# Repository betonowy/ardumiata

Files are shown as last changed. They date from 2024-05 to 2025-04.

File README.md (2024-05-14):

# Engine health monitoring for Mazda MX-5 NB1

Firmware for custom Arduino Nano powered device. Mainly for precise engine health monitoring on track days. Features:

- Invisible, non-invasive piggyback off of factory wiring harness if needed at all.
- Modifications are reversible.
- Cleanly integrates with car's interior. 16x2 green display can replace smoking ashtray on NB1. I made a "mounting bracket" for it with a matte painted piece of wood.
- Monitoring engine health and more:
    - (ECT) Coolant temperature - piggybacked and calibrated against factory sensor and ECU measurement circuit. May alternatively use temp gauge circuit, but you're on your own to deal with that.
    - (EOT) Oil temperatoure - from Ecumaster Temperature Sensor.
    - (EOP) Oil pressure - from Ecumaster Pressure Sensor.
    - (BAT) Battery voltage (from ignition).
- Alarm when any measurement exceeds safe limits so you know when to cooldown or make an emergency shutdown.
- If your ECT ever breaks, you will know.

## Important notes

- ECT approximation function might need to be recalibrated/curve fitted for any other car than mine, especially if any part of PCB design is altered. Measuring temperatures/ECT voltage at the back of the engine with device attached and compensating for measured voltages when fan switches on and off at 97C and 93C is good enough, especially if you just need a relative guide for how hot the engine is. If outside EU, check your regional specs specifically.
- Despite the efforts, cabin fan can offset measurements up to 4 degrees upwards when on and it can't be fixed, take that into account or don't turn it.
- ECT relay is required to ensure device does not affect ECU measurements when device is in an inconsistent state i.e. during reset, or engine startup.
- Cars with no AC have a very convenient rubber cap that can feed wires through passenger side firewall.

# Building project

- PCB project initially made in KiCad 8.
- Source compilled with `avr-gcc` toolchain with Arduino package. For guide check out `Arduino-CMake-NG` project. Initially developed on a Linux system.

Assuming basic KiCad and CMake knowledge, you should already know how to build the project.

## Project layout

- `.` - miscelaneous files and root `CMakeLists.txt`.
- `src` - Firmware source code.
- `kicad` - KiCad PCB project.

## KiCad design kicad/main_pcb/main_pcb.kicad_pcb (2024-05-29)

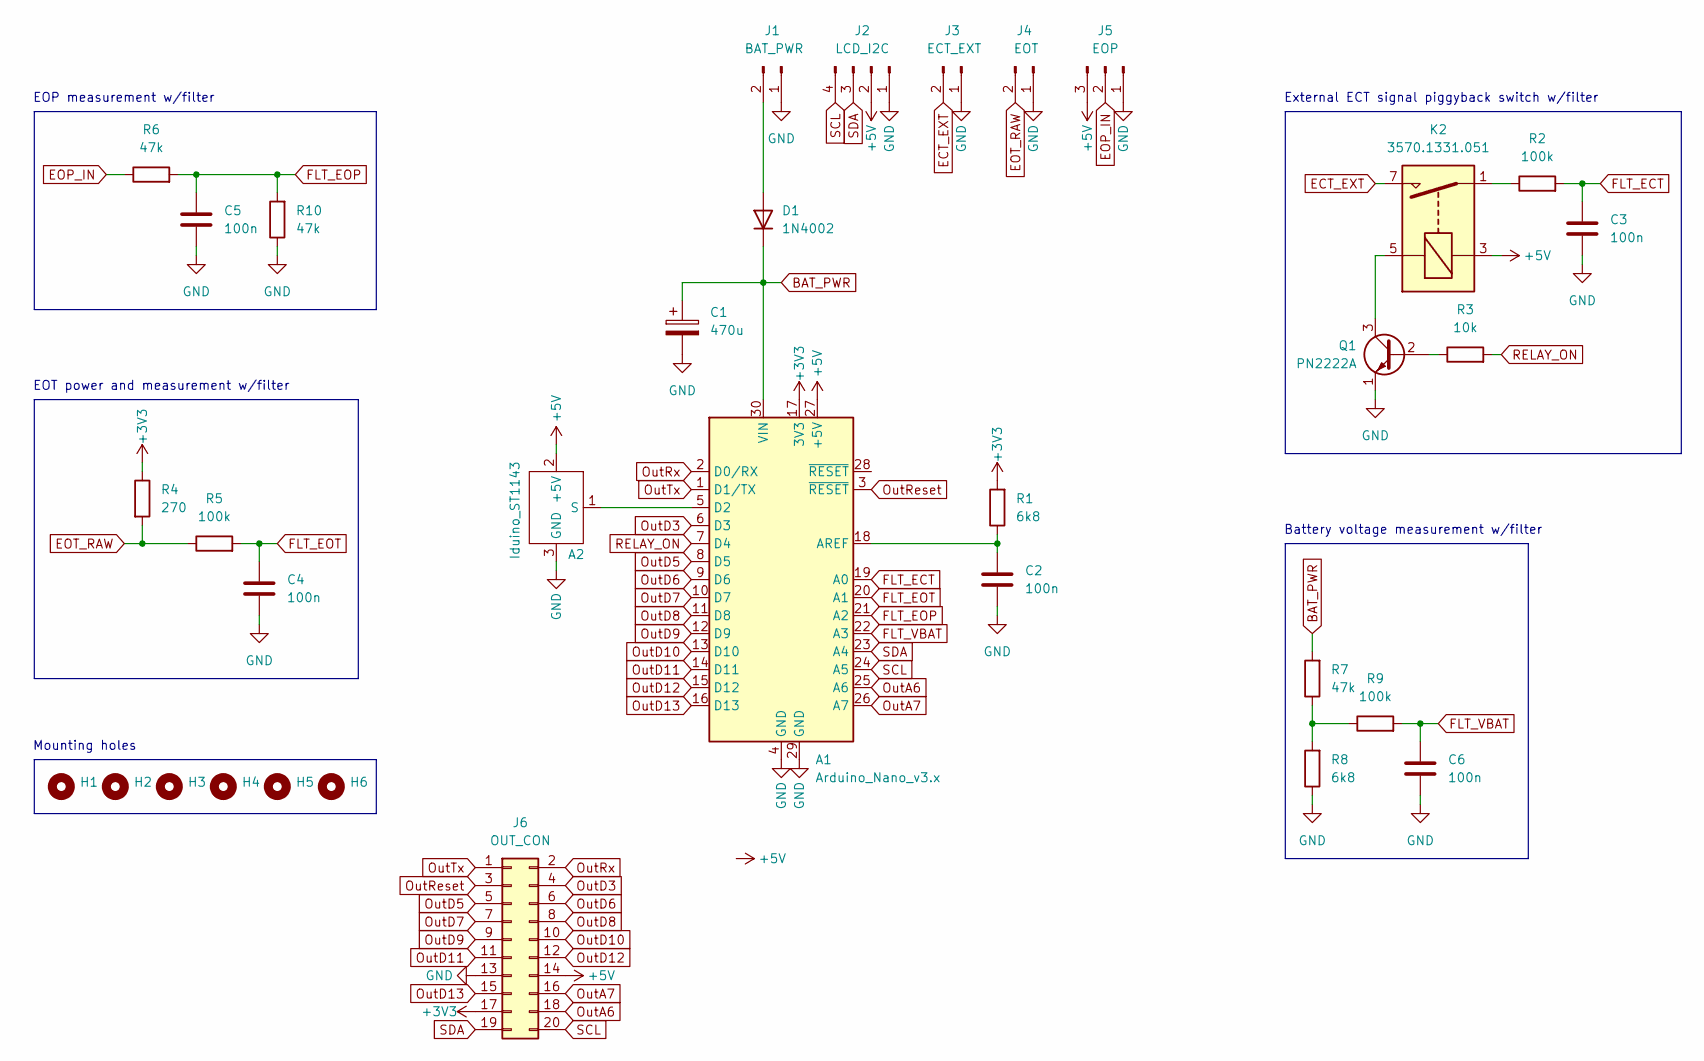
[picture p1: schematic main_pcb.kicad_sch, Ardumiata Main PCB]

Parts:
A1: Arduino_Nano_v3.x; Arduino_Nano
A2: Iduino_ST1143
C1: 470u; CP_Radial_D10.0mm_P5.00mm
C2, C3, C4, C5, C6: 100n; C_Disc_D3.8mm_W2.6mm_P2.50mm
D1: 1N4002; D_DO-41_SOD81_P10.16mm_Horizontal
H1, H2, H3, H4, H5, H6: MountingHole_3.5mm
J1: BAT_PWR; Molex_KK-254_AE-6410-02A_1x02_P2.54mm_Vertical
J2: LCD_I2C; Molex_KK-254_AE-6410-04A_1x04_P2.54mm_Vertical
J3: ECT_EXT; Molex_KK-254_AE-6410-02A_1x02_P2.54mm_Vertical
J4: EOT; Molex_KK-254_AE-6410-02A_1x02_P2.54mm_Vertical
J5: EOP; Molex_KK-254_AE-6410-03A_1x03_P2.54mm_Vertical
J6: OUT_CON; IDC-Header_2x10_P2.54mm_Vertical
K2: 3570.1331.051; Relay_SPST_StandexMeder_SIL_Form1A
Q1: PN2222A; TO-92_Inline
R1, R8: 6k8; R_Axial_DIN0207_L6.3mm_D2.5mm_P7.62mm_Horizontal
R2, R5, R9: 100k; R_Axial_DIN0207_L6.3mm_D2.5mm_P7.62mm_Horizontal
R3: 10k; R_Axial_DIN0207_L6.3mm_D2.5mm_P7.62mm_Horizontal
R4: 270; R_Axial_DIN0207_L6.3mm_D2.5mm_P7.62mm_Horizontal
R6, R7, R10: 47k; R_Axial_DIN0207_L6.3mm_D2.5mm_P7.62mm_Horizontal

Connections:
+3V3: A1.17 (3V3), J6.17, R1.2, R4.1
+5V: A1.27 (+5V), A2.2 (+5V), J2.2, J5.3, J6.14, K2.3
BAT_PWR: A1.30 (VIN), C1.1, D1.1 (K), R7.2
ECT_EXT: J3.2, K2.7
EOP_IN: J5.2, R6.1
EOT_RAW: J4.2, R4.2, R5.1
FLT_ECT: A1.19 (A0), C3.1, R2.2
FLT_EOP: A1.21 (A2), C5.1, R6.2, R10.2
FLT_EOT: A1.20 (A1), C4.1, R5.2
FLT_VBAT: A1.22 (A3), C6.1, R9.2
GND: A1.4 (GND), A1.29 (GND), A2.3 (GND), C1.2, C2.2, C3.2, C4.2, C5.2, C6.2, J1.1, J2.1, J3.1, J4.1, J5.1, J6.13, Q1.1 (E), R8.1, R10.1
unnamed: A1.18 (AREF), C2.1, R1.1
unnamed: A1.5 (D2), A2.1 (S)
unnamed: D1.2 (A), J1.2
unnamed: K2.1, R2.1
unnamed: Q1.2 (B), R3.1
unnamed: K2.5, Q1.3 (C)
unnamed: R7.1, R8.2, R9.1
OutA6: A1.25 (A6), J6.18
OutA7: A1.26 (A7), J6.16
OutD3: A1.6 (D3), J6.4
OutD5: A1.8 (D5), J6.5
OutD6: A1.9 (D6), J6.6
OutD7: A1.10 (D7), J6.7
OutD8: A1.11 (D8), J6.8
OutD9: A1.12 (D9), J6.9
OutD10: A1.13 (D10), J6.10
OutD11: A1.14 (D11), J6.11
OutD12: A1.15 (D12), J6.12
OutD13: A1.16 (D13), J6.15
OutReset: A1.3 (~RESET), J6.3
OutRx: A1.2 (D0/RX), J6.2
OutTx: A1.1 (D1/TX), J6.1
RELAY_ON: A1.7 (D4), R3.2
SCL: A1.24 (A5), J2.4, J6.20
SDA: A1.23 (A4), J2.3, J6.19

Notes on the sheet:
EOP measurement w/filter
Battery voltage measurement w/filter
External ECT signal piggyback switch w/filter
Mounting holes
EOT power and measurement w/filter

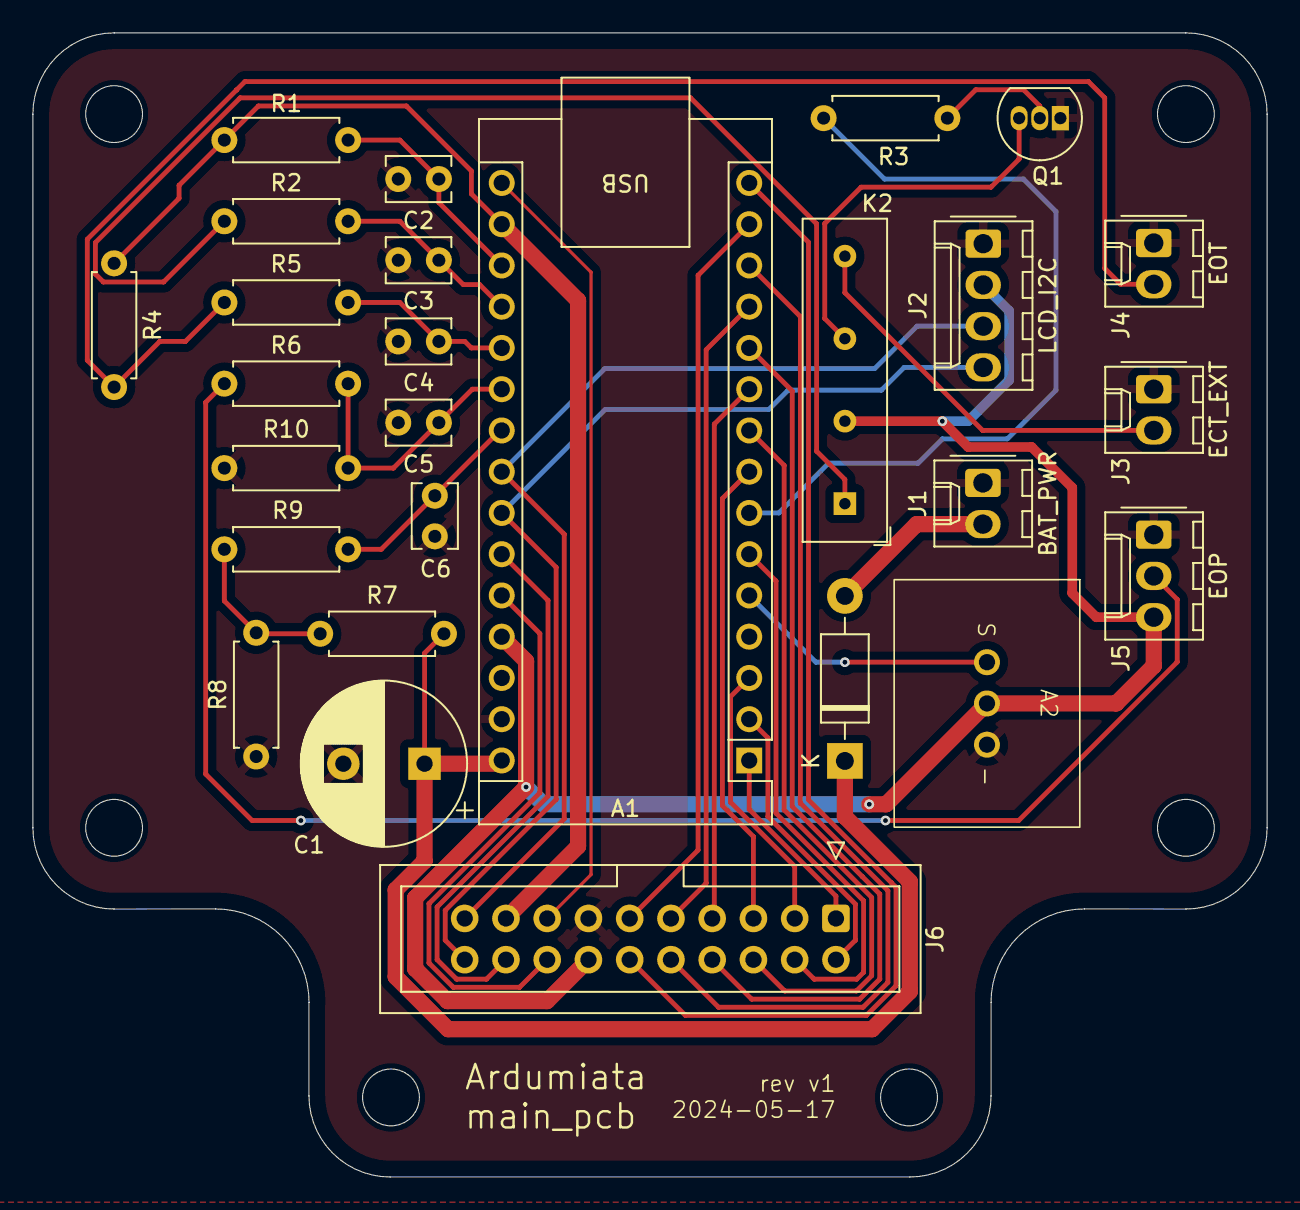
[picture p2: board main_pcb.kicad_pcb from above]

Board: 2 copper layers, 76.0 x 70.4 mm, 33 parts (0 on the bottom side), 36 nets.

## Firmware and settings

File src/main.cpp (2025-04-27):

#include <Arduino.h>

#include "buzzer.hpp"
#include "display.hpp"
#include "sensors.hpp"
#include "voltage.hpp"

void setup()
{
    analogReference(EXTERNAL);
    setupBuzzer();
    setupDisplay();

    pinMode(4, OUTPUT);
    digitalWrite(4, HIGH);

    // Beep to signal setup completion
    setBuzzer(true);
    delay(30);
    setBuzzer(false);
}

void updatePeriodicalReadings()
{
    ectUpdateRaw(hardenedAnalogRead(A0));
    eotUpdateRaw(hardenedAnalogRead(A1));
    eopUpdateRaw(hardenedAnalogRead(A2));

    {
        setSlotIcon(DisplaySlot::UL, Icon::OIL, Icon::TEMP);

        switch (eotIsValid())
        {
        case SensorRange::OK:
            setSlot(DisplaySlot::UL, eotGetCelsius());
            break;
        case SensorRange::TOO_LOW:
            setSlot(DisplaySlot::UL, "Cold");
            break;
        case SensorRange::TOO_HIGH:
            setSlot(DisplaySlot::UL, "Hot");
        }
    }
    {
        setSlotIcon(DisplaySlot::UR, Icon::OIL, Icon::PRESSURE);

        switch (eopIsValid())
        {
        case SensorRange::OK:
        case SensorRange::OK_DISABLE_ALARM:
            setSlot(DisplaySlot::UR, eopGetBar());
            break;
        case SensorRange::TOO_LOW:
            setSlot(DisplaySlot::UR, 0.0f);
            break;
        case SensorRange::TOO_HIGH:
            setSlot(DisplaySlot::UR, 10.0f);
        }
    }
    {
        setSlotIcon(DisplaySlot::BL, Icon::WATER, Icon::TEMP);

        switch (ectIsValid())
        {
        case SensorRange::OK:
            setSlot(DisplaySlot::BL, ectGetCelsius());
            break;
        case SensorRange::TOO_LOW:
            setSlot(DisplaySlot::BL, "Cold");
            break;
        case SensorRange::TOO_HIGH:
            setSlot(DisplaySlot::BL, "Hot");
        }
    }
    {
        setSlotIcon(DisplaySlot::BR, Icon::BAT_A, Icon::BAT_B);
        setSlot(DisplaySlot::BR, getVoltage());
    }
}

namespace
{
constexpr auto safeCoolantTempLimit = 115.f;
constexpr auto safeOilTempLimit = 130.f;
constexpr auto safePressureLimitLow = 0.65f;
constexpr auto safePressureLimitHigh = 6.0f;
} // namespace

void updateAlarm()
{
    bool turnOnAlarm = false;

    turnOnAlarm |= ectGetCelsius() > safeCoolantTempLimit && ectIsValid() == SensorRange::OK;
    turnOnAlarm |= eotGetCelsius() > safeOilTempLimit && eotIsValid() == SensorRange::OK;
    turnOnAlarm |= eopGetBar() > safePressureLimitHigh && eopIsValid() == SensorRange::OK;
    turnOnAlarm |= eopGetBar() < safePressureLimitLow && eopIsValid() == SensorRange::OK;

    if (turnOnAlarm)
    {
        setBuzzer(true);
    }
    else
    {
        setBuzzer(false);
    }
}

unsigned long nextUpdateTime = 0;
unsigned long screenDelay = 250;

bool shouldUpdateDisplay()
{
    const uint32_t time = millis();

    if (static_cast<int32_t>(nextUpdateTime - time) > 0)
    {
        return false;
    }

    nextUpdateTime = time + screenDelay;

    return true;
}

void loop()
{
    if (shouldUpdateDisplay())
    {
        updatePeriodicalReadings();
        updateDisplay();
        updateAlarm();
    }

    loopBuzzer();
}

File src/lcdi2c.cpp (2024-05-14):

#include "lcdi2c.hpp"
#include <Arduino.h>
#include <Wire.h>

// When the display powers up, it is configured as follows:
//
// 1. Display clear
// 2. Function set:
//    DL = 1; 8-bit interface data
//    N = 0; 1-line display
//    F = 0; 5x8 dot character font
// 3. Display on/off control:
//    D = 0; Display off
//    C = 0; Cursor off
//    B = 0; Blinking off
// 4. Entry mode set:
//    I/D = 1; Increment by 1
//    S = 0; No shift
//
// Note, however, that resetting the Arduino doesn't reset the LCD, so we
// can't assume that its in that state when a sketch starts (and the
// LiquidCrystal constructor is called).

LiquidCrystal_I2C::LiquidCrystal_I2C(uint8_t lcd_addr, uint8_t lcd_cols, uint8_t lcd_rows, uint8_t charsize)
{
    _addr = lcd_addr;
    _cols = lcd_cols;
    _rows = lcd_rows;
    _charsize = charsize;
    _backlightval = LCD_BACKLIGHT;
}

void LiquidCrystal_I2C::begin()
{
    Wire.begin();
    _displayfunction = LCD_4BITMODE | LCD_1LINE | LCD_5x8DOTS;

    if (_rows > 1)
    {
        _displayfunction |= LCD_2LINE;
    }

    // for some 1 line displays you can select a 10 pixel high font
    if ((_charsize != 0) && (_rows == 1))
    {
        _displayfunction |= LCD_5x10DOTS;
    }

    // SEE PAGE 45/46 FOR INITIALIZATION SPECIFICATION!
    // according to datasheet, we need at least 40ms after power rises above 2.7V
    // before sending commands. Arduino can turn on way befer 4.5V so we'll wait 50
    delay(50);

    // Now we pull both RS and R/W low to begin commands
    expanderWrite(_backlightval); // reset expanderand turn backlight off (Bit 8 =1)
    delay(1000);

    // put the LCD into 4 bit mode
    //  this is according to the hitachi HD44780 datasheet
    //  figure 24, pg 46

    // we start in 8bit mode, try to set 4 bit mode
    write4bits(0x03 << 4);
    delayMicroseconds(4500); // wait min 4.1ms

    // second try
    write4bits(0x03 << 4);
    delayMicroseconds(4500); // wait min 4.1ms

    // third go!
    write4bits(0x03 << 4);
    delayMicroseconds(150);

    // finally, set to 4-bit interface
    write4bits(0x02 << 4);

    // set # lines, font size, etc.
    command(LCD_FUNCTIONSET | _displayfunction);

    // turn the display on with no cursor or blinking default
    _displaycontrol = LCD_DISPLAYON | LCD_CURSOROFF | LCD_BLINKOFF;
    display();

    // clear it off
    clear();

    // Initialize to default text direction (for roman languages)
    _displaymode = LCD_ENTRYLEFT | LCD_ENTRYSHIFTDECREMENT;

    // set the entry mode
    command(LCD_ENTRYMODESET | _displaymode);

    home();
}

/********** high level commands, for the user! */
void LiquidCrystal_I2C::clear()
{
    command(LCD_CLEARDISPLAY); // clear display, set cursor position to zero
    delayMicroseconds(2000);   // this command takes a long time!
}

void LiquidCrystal_I2C::home()
{
    command(LCD_RETURNHOME); // set cursor position to zero
    delayMicroseconds(2000); // this command takes a long time!
}

void LiquidCrystal_I2C::setCursor(uint8_t col, uint8_t row)
{
    int row_offsets[] = {0x00, 0x40, 0x14, 0x54};
    if (row > _rows)
    {
        row = _rows - 1; // we count rows starting w/0
    }
    command(LCD_SETDDRAMADDR | (col + row_offsets[row]));
}

// Turn the display on/off (quickly)
void LiquidCrystal_I2C::noDisplay()
{
    _displaycontrol &= ~LCD_DISPLAYON;
    command(LCD_DISPLAYCONTROL | _displaycontrol);
}
void LiquidCrystal_I2C::display()
{
    _displaycontrol |= LCD_DISPLAYON;
    command(LCD_DISPLAYCONTROL | _displaycontrol);
}

// Turns the underline cursor on/off
void LiquidCrystal_I2C::noCursor()
{
    _displaycontrol &= ~LCD_CURSORON;
    command(LCD_DISPLAYCONTROL | _displaycontrol);
}
void LiquidCrystal_I2C::cursor()
{
    _displaycontrol |= LCD_CURSORON;
    command(LCD_DISPLAYCONTROL | _displaycontrol);
}

// Turn on and off the blinking cursor
void LiquidCrystal_I2C::noBlink()
{
    _displaycontrol &= ~LCD_BLINKON;
    command(LCD_DISPLAYCONTROL | _displaycontrol);
}
void LiquidCrystal_I2C::blink()
{
    _displaycontrol |= LCD_BLINKON;
    command(LCD_DISPLAYCONTROL | _displaycontrol);
}

// These commands scroll the display without changing the RAM
void LiquidCrystal_I2C::scrollDisplayLeft(void)
{
    command(LCD_CURSORSHIFT | LCD_DISPLAYMOVE | LCD_MOVELEFT);
}
void LiquidCrystal_I2C::scrollDisplayRight(void)
{
    command(LCD_CURSORSHIFT | LCD_DISPLAYMOVE | LCD_MOVERIGHT);
}

// This is for text that flows Left to Right
void LiquidCrystal_I2C::leftToRight(void)
{
    _displaymode |= LCD_ENTRYLEFT;
    command(LCD_ENTRYMODESET | _displaymode);
}

// This is for text that flows Right to Left
void LiquidCrystal_I2C::rightToLeft(void)
{
    _displaymode &= ~LCD_ENTRYLEFT;
    command(LCD_ENTRYMODESET | _displaymode);
}

// This will 'right justify' text from the cursor
void LiquidCrystal_I2C::autoscroll(void)
{
    _displaymode |= LCD_ENTRYSHIFTINCREMENT;
    command(LCD_ENTRYMODESET | _displaymode);
}

// This will 'left justify' text from the cursor
void LiquidCrystal_I2C::noAutoscroll(void)
{
    _displaymode &= ~LCD_ENTRYSHIFTINCREMENT;
    command(LCD_ENTRYMODESET | _displaymode);
}

// Allows us to fill the first 8 CGRAM locations
// with custom characters
void LiquidCrystal_I2C::createChar(uint8_t location, const uint8_t charmap[])
{
    location &= 0x7; // we only have 8 locations 0-7
    command(LCD_SETCGRAMADDR | (location << 3));
    for (int i = 0; i < 8; i++)
    {
        write(charmap[i]);
    }
}

// Turn the (optional) backlight off/on
void LiquidCrystal_I2C::noBacklight(void)
{
    _backlightval = LCD_NOBACKLIGHT;
    expanderWrite(0);
}

void LiquidCrystal_I2C::backlight(void)
{
    _backlightval = LCD_BACKLIGHT;
    expanderWrite(0);
}
bool LiquidCrystal_I2C::getBacklight()
{
    return _backlightval == LCD_BACKLIGHT;
}

/*********** mid level commands, for sending data/cmds */

inline void LiquidCrystal_I2C::command(uint8_t value)
{
    send(value, 0);
}

inline size_t LiquidCrystal_I2C::write(uint8_t value)
{
    send(value, Rs);
    return 1;
}

/************ low level data pushing commands **********/

// write either command or data
void LiquidCrystal_I2C::send(uint8_t value, uint8_t mode)
{
    uint8_t highnib = value & 0xf0;
    uint8_t lownib = (value << 4) & 0xf0;
    write4bits((highnib) | mode);
    write4bits((lownib) | mode);
}

void LiquidCrystal_I2C::write4bits(uint8_t value)
{
    expanderWrite(value);
    pulseEnable(value);
}

void LiquidCrystal_I2C::expanderWrite(uint8_t _data)
{
    Wire.beginTransmission(_addr);
    Wire.write((int)(_data) | _backlightval);
    Wire.endTransmission();
}

void LiquidCrystal_I2C::pulseEnable(uint8_t _data)
{
    expanderWrite(_data | En); // En high
    delayMicroseconds(1);      // enable pulse must be >450ns

    expanderWrite(_data & ~En); // En low
    delayMicroseconds(50);      // commands need > 37us to settle
}

void LiquidCrystal_I2C::load_custom_character(uint8_t char_num, uint8_t *rows)
{
    createChar(char_num, rows);
}
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

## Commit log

2024-05-01 Working prototype
2024-05-01 Battery state and buzzer support
    [main.cpp]
2024-05-06 Debug features, sensor test
2024-05-06 Badly calibrated EOT, but it's a start
2024-05-14 EOT, EOP implementation and calibration
2024-05-14 Add KiCad PCB project
    [main_pcb.kicad_pcb, main_pcb.kicad_sch]
2024-05-18 Main PCB final design, refine eot calibration and limits
    [main_pcb.kicad_pcb, main_pcb.kicad_sch]
2024-05-29 Component adjustments and recalibration
    [main_pcb.kicad_pcb, main_pcb.kicad_sch]
2024-06-01 Don't trigger oil pressure alarm when the engine is off
2025-04-27 Change high pressure limit to avoid alarms at winter
    [main.cpp]

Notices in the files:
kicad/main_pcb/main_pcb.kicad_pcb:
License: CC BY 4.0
